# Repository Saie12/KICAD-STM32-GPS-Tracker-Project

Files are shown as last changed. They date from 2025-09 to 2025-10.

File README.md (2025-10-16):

# STM32 Cellular GPS Asset Tracker

A robust, open-source hardware platform for real-time vehicle and asset tracking, featuring an STM32 microcontroller, dedicated GPS/GNSS for positioning, and a GSM module for cellular data transmission.

## Project Overview

This project is a compact, feature-rich hardware solution designed for real-time asset tracking. The board integrates a powerful STMicroelectronics STM32 microcontroller with dedicated GPS/GNSS and GSM cellular modules. Its primary function is to acquire precise location coordinates from satellite systems and transmit this data, along with other potential sensor readings, to a remote server or cloud platform over the cellular network.

Engineered for reliability in mobile environments, the board is designed to be powered from a common 12V source, making it ideal for a wide range of applications, including:

*   Vehicle and fleet management
*   High-value asset monitoring and security
*   Logistics and supply chain tracking
*   Geofencing and location-based alerts

## Key Features

*   **Powerful MCU Core:** Utilizes an ARM Cortex-M based **STM32 microcontroller** for all processing, logic, and peripheral management.
*   **High-Precision Positioning:** Integrates a dedicated **GPS/GNSS module** for accurate and reliable location acquisition.
*   **Global Cellular Connectivity:** Features a **GSM/GPRS module** with a standard SIM card interface for sending data from anywhere with cellular coverage.
*   **Wide Voltage Input:** Accepts a **12V DC power input**, suitable for direct integration into automotive and industrial systems.
*   **Sensor Expansion:** On-board **SPI and I2C interfaces** are broken out, allowing for easy expansion with sensors like accelerometers, gyroscopes, temperature/humidity sensors, and more.
*   **Standard Debug Interface:** Includes a **Serial Wire Debug (SWD)** header for straightforward firmware programming and in-circuit debugging.

## Technical Deep Dive

### System Architecture

The hardware architecture is centered around the STM32 MCU, which acts as the brain of the system. It orchestrates all operations:

1.  **GPS Data Acquisition:** The MCU communicates with the GPS module (typically over a UART serial bus) to receive and parse standard NMEA sentences, extracting critical data such as latitude, longitude, altitude, speed, and time.
2.  **Cellular Modem Management:** The MCU controls the GSM module using AT commands sent over a second UART. It manages the SIM card connection, establishes a GPRS data session, and transmits formatted data packets (e.g., via HTTP or MQTT) to a configured backend server.
3.  **Power Management:** An on-board switching regulator efficiently steps down the 12V input to a stable 3.3V rail required by the MCU and other sensitive digital components.

### RF & PCB Design

Handling two separate RF systems on a compact board requires careful design considerations.

*   **RF Traces:** The traces connecting the GPS and GSM modules to their respective external antenna connectors (`GPS_ANT` and `GSM_ANT`) are designed as 50-ohm controlled impedance transmission lines. This is crucial for minimizing signal loss and maximizing RF performance.
*   **4-Layer PCB:** The design utilizes a 4-layer printed circuit board. This allows for dedicated signal, ground, and power layers, which is essential for:
    *   **Noise Reduction:** A solid ground plane provides excellent shielding and a low-inductance return path for high-speed signals, isolating the sensitive RF components from digital noise.
    *   **Signal Integrity:** Ensures clean, reliable communication between all components.
    *   **Compact Routing:** Enables a denser and more compact physical layout.

*   **Design Note:** For optimal RF performance and EMI/EMC compliance, the layer stackup should be configured as `Signal - Ground - Power - Signal`. Dedicating an entire inner layer to an uninterrupted ground plane is a best practice for mixed-signal RF designs like this one.

## Getting Started

To use this board, you will need:

1.  A **12V DC** power supply.
2.  An active **SIM card** with a data plan.
3.  External **GPS and GSM antennas** with appropriate connectors.
4.  An **ST-Link** or similar SWD programmer to flash the firmware onto the STM32 MCU.
5.  Custom firmware to read the GPS data, format it, and send it to your desired server endpoint via the GSM module.

---
```

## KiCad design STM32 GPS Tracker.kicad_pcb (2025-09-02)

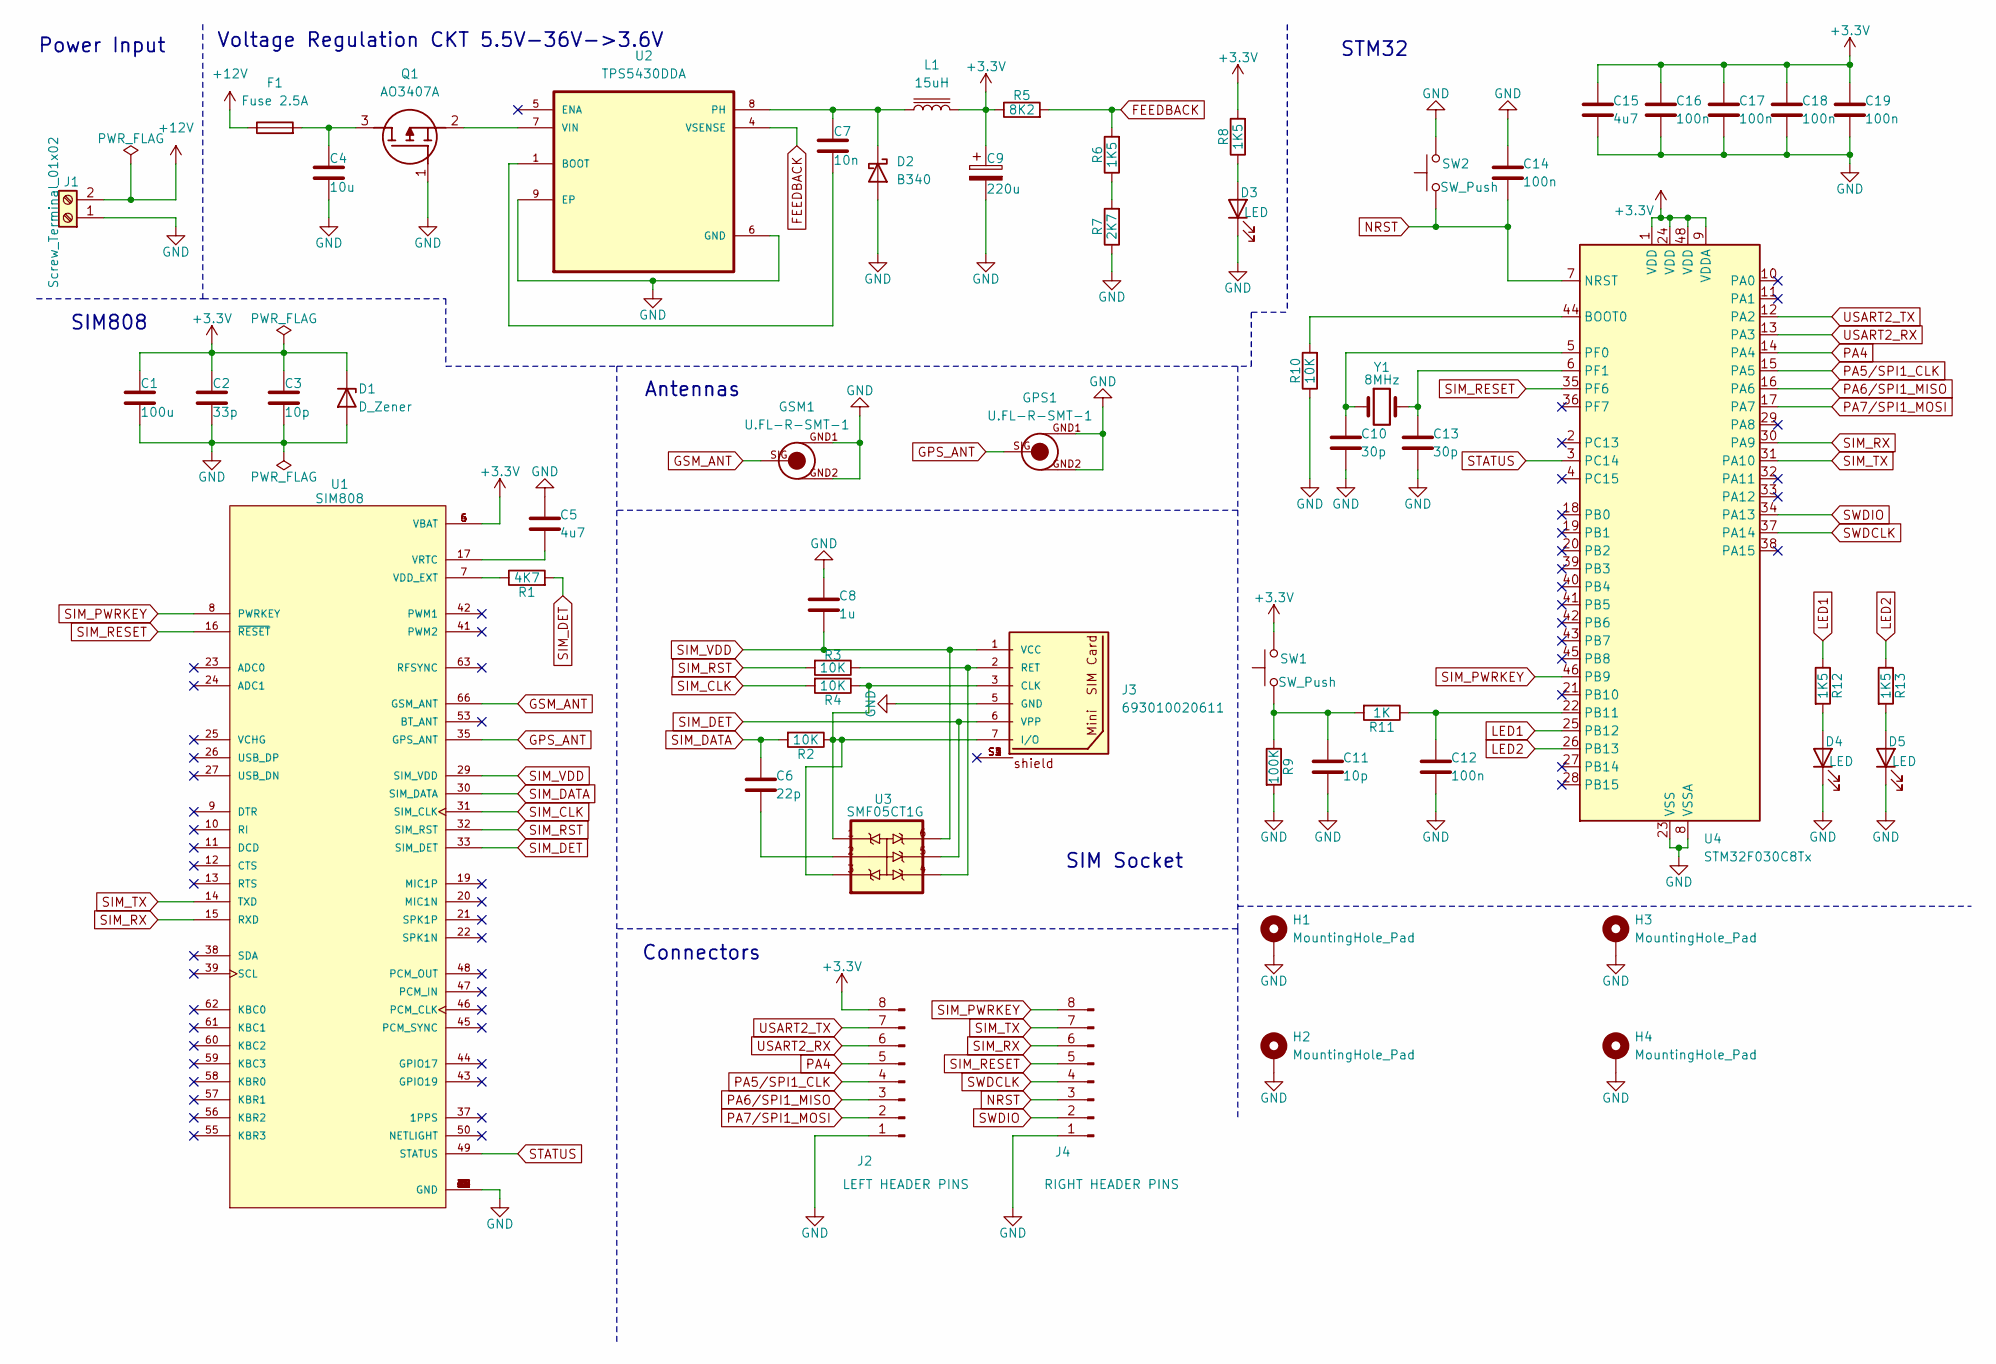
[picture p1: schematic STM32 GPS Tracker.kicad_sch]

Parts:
C1: 100u; C_1206_3216Metric
C2: 33p; C_0402_1005Metric
C3, C11: 10p; C_0402_1005Metric
C4: 10u; C_0805_2012Metric
C5, C15: 4u7; C_0201_0603Metric
C6: 22p; C_0402_1005Metric
C7: 10n; C_0201_0603Metric
C8: 1u; C_0402_1005Metric
C9: 220u; CP_EIA-7343-15_Kemet-W
C10, C13: 30p; C_0402_1005Metric
C12, C14, C16, C17, C18, C19: 100n; C_0402_1005Metric
D1: D_Zener; D_0805_2012Metric
D2: B340; D_SMC
D3, D4, D5: LED; LED_0201_0603Metric
F1: Fuse 2.5A; Fuse_0402_1005Metric
GPS1: U.FL-R-SMT-1
GSM1: U.FL-R-SMT-1
H1, H2, H3, H4: MountingHole_Pad; MountingHole_2.2mm_M2_Pad_Via
J1: Screw_Terminal_01x02; TerminalBlock_bornier-2_P5.08mm
J2: LEFT HEADER PINS; PinHeader_1x08_P2.54mm_Vertical
J3: 693010020611; PART-NUMBER 693010020611
J4: RIGHT HEADER PINS; PinHeader_1x08_P2.54mm_Vertical
L1: 15uH; L_10.4x10.4_H4.8
Q1: AO3407A; SOT95P280X125-3N; Manufacturer_Part_Number AO3407A
R1: 4K7; R_0402_1005Metric
R2, R3, R4, R10: 10K; R_0402_1005Metric
R5: 8K2; R_0805_2012Metric
R6, R8, R12, R13: 1K5; R_0805_2012Metric
R7: 2K7; R_0805_2012Metric
R9: 100K; R_0201_0603Metric
R11: 1K; R_0603_1608Metric
SW1, SW2: SW_Push; SW_Push_1P1T_NO_CK_KSC6xxJ
U1: SIM808; XCVR_SIM808; PARTREV 1.03
U2: TPS5430DDA; VREG_LM5017MR_NOPB
U3: SMF05CT1G; SOT65P210X110-6N
U4: STM32F030C8Tx; LQFP-48_7x7mm_P0.5mm
Y1: 8MHz; Crystal_SMD_5032-2Pin_5.0x3.2mm

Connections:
+3.3V: C1.1, C2.1, C3.1, C9.1, C15.1, C16.1, C17.1, C18.1, C19.1, D1.1 (K), J2.8, L1.2, R5.1, R8.2, SW1.2, U1.4 (VBAT), U1.5 (VBAT), U1.6 (VBAT), U4.1 (VDD), U4.9 (VDDA), U4.24 (VDD), U4.48 (VDD)
+12V: F1.1, J1.2
FEEDBACK: R5.2, R6.2, U2.4 (VSENSE)
GND: C1.2, C2.2, C3.2, C4.2, C5.1, C8.1, C9.2, C10.2, C11.2, C12.2, C13.2, C14.1, C15.2, C16.2, C17.2, C18.2, C19.2, D1.2 (A), D2.2 (A), D3.1 (K), D4.1 (K), D5.1 (K), GPS1.GND1, GPS1.GND2, GSM1.GND1, GSM1.GND2, H1.1, H2.1, H3.1, H4.1, J1.1, J2.1, J3.5 (GND), J4.1, Q1.1 (G), R7.1, R9.2, R10.1, SW2.2, U1.1 (GND), U1.2 (GND), U1.3 (GND), U1.18 (GND), U1.28 (GND), U1.34 (GND), U1.36 (GND), U1.40 (GND), U1.51 (GND), U1.52 (GND), U1.54 (GND), U1.64 (GND), U1.65 (GND), U1.67 (GND), U1.68 (GND), U2.6 (GND), U2.9 (EP), U4.8 (VSSA), U4.23 (VSS), U4.47 (VSS)
GPS_ANT: GPS1.SIG, U1.35 (GPS_ANT)
GSM_ANT: GSM1.SIG, U1.66 (GSM_ANT)
LED1: R12.1, U4.25 (PB12)
LED2: R13.1, U4.26 (PB13)
NRST: C14.2, J4.3, SW2.1, U4.7 (NRST)
unnamed: C6.2, U3.2
unnamed: C11.1, R9.1, R11.2, SW1.1
unnamed: C7.1, D2.1 (K), L1.1, U2.8 (PH)
unnamed: D3.2 (A), R8.1
unnamed: D4.2 (A), R12.2
unnamed: D5.2 (A), R13.2
unnamed: J3.3 (CLK), J3.7 (I/O), R2.1, R4.1, U3.1, U3.3
unnamed: J3.2 (RET), R3.1, U3.4
unnamed: C4.1, F1.2, Q1.3 (D)
unnamed: Q1.2 (S), U2.7 (VIN)
unnamed: R6.1, R7.2
unnamed: R1.1, U1.7 (VDD_EXT)
unnamed: C5.2, U1.17 (VRTC)
unnamed: C7.2, U2.1 (BOOT)
unnamed: R10.2, U4.44 (BOOT0)
unnamed: C12.1, R11.1, U4.22 (PB11)
unnamed: C10.1, U4.5 (PF0), Y1.1
unnamed: C13.1, U4.6 (PF1), Y1.2
PA4: J2.5, U4.14 (PA4)
PA5/SPI1_CLK: J2.4, U4.15 (PA5)
PA6/SPI1_MISO: J2.3, U4.16 (PA6)
PA7/SPI1_MOSI: J2.2, U4.17 (PA7)
SIM_CLK: R4.2, U1.31 (SIM_CLK)
SIM_DATA: C6.1, R2.2, U1.30 (SIM_DATA)
SIM_DET: J3.6 (VPP), R1.2, U1.33 (SIM_DET), U3.5
SIM_PWRKEY: J4.8, U1.8 (PWRKEY), U4.46 (PB9)
SIM_RESET: J4.5, U1.16 (~RESET), U4.35 (PF6)
SIM_RST: R3.2, U1.32 (SIM_RST)
SIM_RX: J4.6, U1.15 (RXD), U4.30 (PA9)
SIM_TX: J4.7, U1.14 (TXD), U4.31 (PA10)
SIM_VDD: C8.2, J3.1 (VCC), U1.29 (SIM_VDD), U3.6
STATUS: U1.49 (STATUS), U4.3 (PC14)
SWDCLK: J4.4, U4.37 (PA14)
SWDIO: J4.2, U4.34 (PA13)
USART2_RX: J2.6, U4.13 (PA3)
USART2_TX: J2.7, U4.12 (PA2)

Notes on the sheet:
Voltage Regulation CKT 5.5V-36V->3.6V
Connectors
STM32
SIM Socket
Power Input
SIM808
Antennas

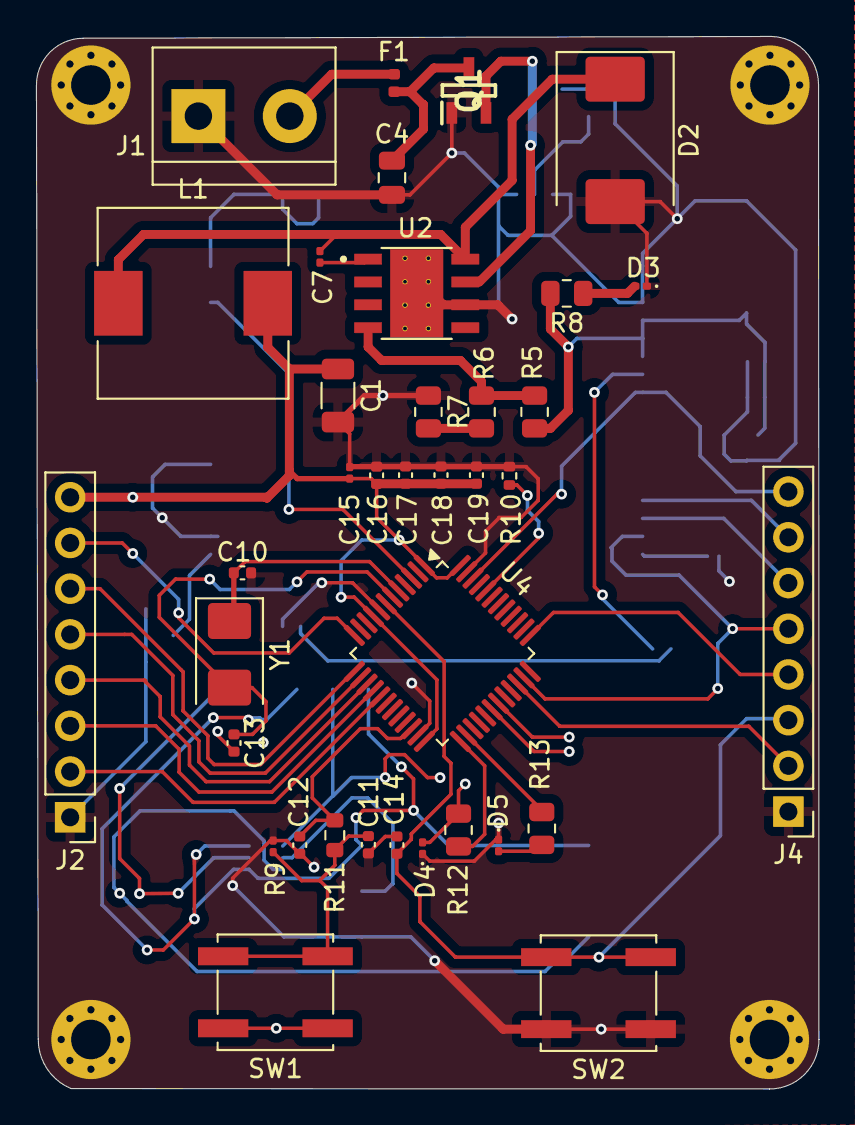
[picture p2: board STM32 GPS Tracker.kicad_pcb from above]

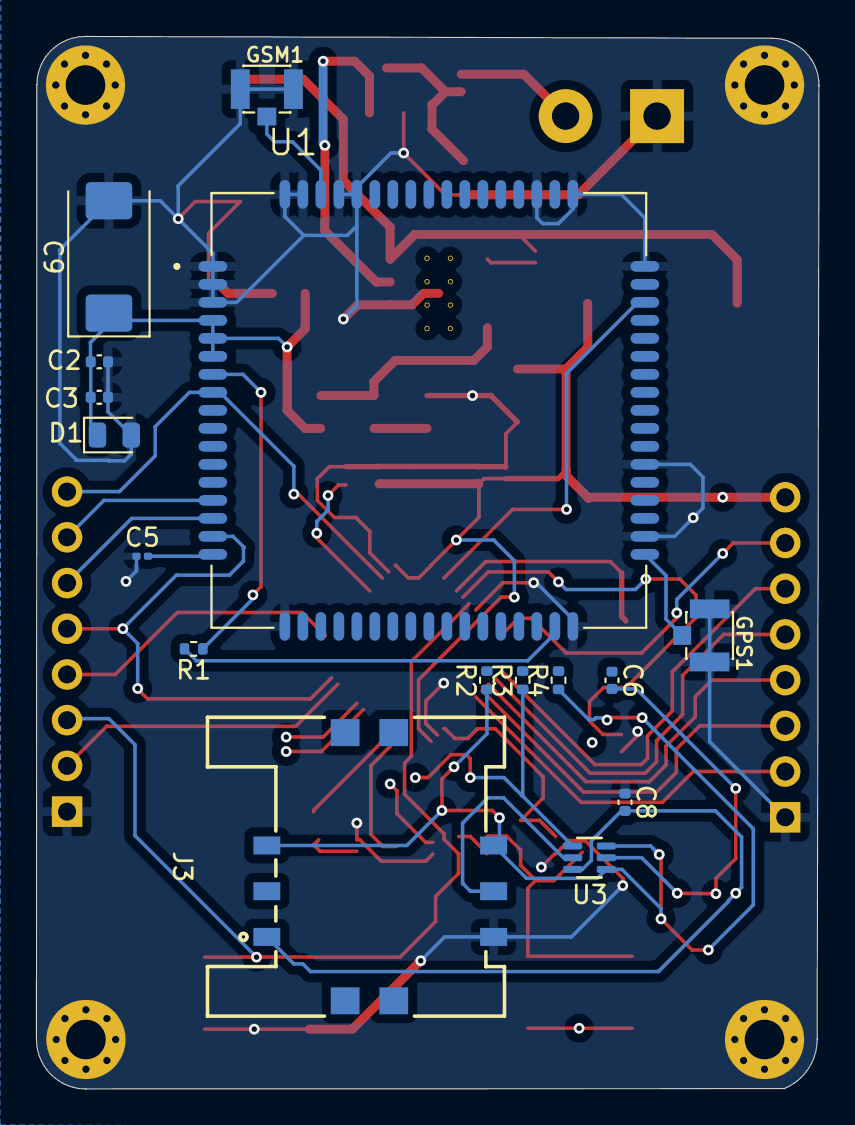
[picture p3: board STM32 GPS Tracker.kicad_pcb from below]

Board: 4 copper layers, 43.5 x 58.5 mm, 57 parts (16 on the bottom side), 45 nets.

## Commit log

2025-08-26 Push Initial Files to Repository
    [STM32 GPS Tracker.kicad_pcb, STM32 GPS Tracker.kicad_sch]
2025-08-27 Placed MCU STM-32 in Schematic
    [STM32 GPS Tracker.kicad_sch]
2025-08-27 Added external Library to Library folder - SIM808
    [STM32 GPS Tracker.kicad_sch]
2025-08-27 Added External Library to Libraries folder - 693010020611 Header for Mini SIM card
    [STM32 GPS Tracker.kicad_sch]
2025-08-27 Added External Library to Libraries folder - A03407A MOSFET
2025-08-27 Added External Library to Libraries folder - SMF05CT1G
    [STM32 GPS Tracker.kicad_sch]
2025-08-27 Added External Library to Libraries folder - TPS5430DDA Switching Regulator
2025-08-27 Added External Library to Libraries folder - U.FL-R-SMT-1 RF Connector
    [STM32 GPS Tracker.kicad_sch]
2025-08-28 Schematic for SIM808 completed
    [STM32 GPS Tracker.kicad_sch]
2025-08-28 Placing and wiring components for Voltage regulation ckt in Schematic
    [STM32 GPS Tracker.kicad_sch]
2025-08-28 remaining Placing and wiring components for Voltage regulation ckt in Schematic
    [STM32 GPS Tracker.kicad_sch]
2025-08-29 Completed Placing and wiring components for Voltage regulation ckt in Schematic
    [STM32 GPS Tracker.kicad_sch]
2025-08-29 Completed Placing and Wiring components for SIM SOCKET in Schematic
    [STM32 GPS Tracker.kicad_sch]
2025-08-29 Placing and wiring components for STM32 ckt in Schematic
    [STM32 GPS Tracker.kicad_sch]
2025-08-29 Remaining Placing and wiring components for STM32 ckt in Schematic
    [STM32 GPS Tracker.kicad_sch]
2025-08-29 Completed Placing and wiring components for STM32 ckt in Schematic
    [STM32 GPS Tracker.kicad_sch]
2025-08-29 Completed Placing and wiring components for Power Input ckt in Schematic
    [STM32 GPS Tracker.kicad_sch]
2025-08-29 Completed Placing and wiring components for Connectors ckt in Schematic
    [STM32 GPS Tracker.kicad_sch]
2025-08-29 Placed the Lines in Schematic
    [STM32 GPS Tracker.kicad_sch]
2025-08-29 Placed the Texts in Schematic
    [STM32 GPS Tracker.kicad_sch]
2025-08-31 Assigned the Footprints
    [STM32 GPS Tracker.kicad_pcb, STM32 GPS Tracker.kicad_sch]
2025-08-31 Proper placing and edge cuts done for the Footprints
    [STM32 GPS Tracker.kicad_pcb]
2025-08-31 Round Cornering
    [STM32 GPS Tracker.kicad_pcb]
2025-08-31 Routing the Top Signal Layers -Incomplete (In Progress)
    [STM32 GPS Tracker.kicad_pcb]
2025-09-01 Completed Tracks for Front Copper Layer
    [STM32 GPS Tracker.kicad_pcb]
2025-09-01 Remaining Tracks for Back Copper Layer (In Progress)
    [STM32 GPS Tracker.kicad_pcb, freerouting.dsn, temp-freerouting.dsn]
2025-09-02 Completed the Bottom Copper Layer
    [STM32 GPS Tracker.kicad_pcb]
2025-09-02 Completed the Layer 1
    [STM32 GPS Tracker.kicad_pcb]
2025-09-02 Completed the 3D model
    [STM32 GPS Tracker.kicad_pcb]
2025-10-16 Initialize README with project details and instructions
    Added detailed project overview, key features, technical architecture, and getting started instructions for the STM32 Cellular GPS Asset Tracker.
